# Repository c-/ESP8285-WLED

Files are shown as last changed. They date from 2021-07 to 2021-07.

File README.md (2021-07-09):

This is a WLED board built around an ESP-8285, designed to be milled on
a CNC.

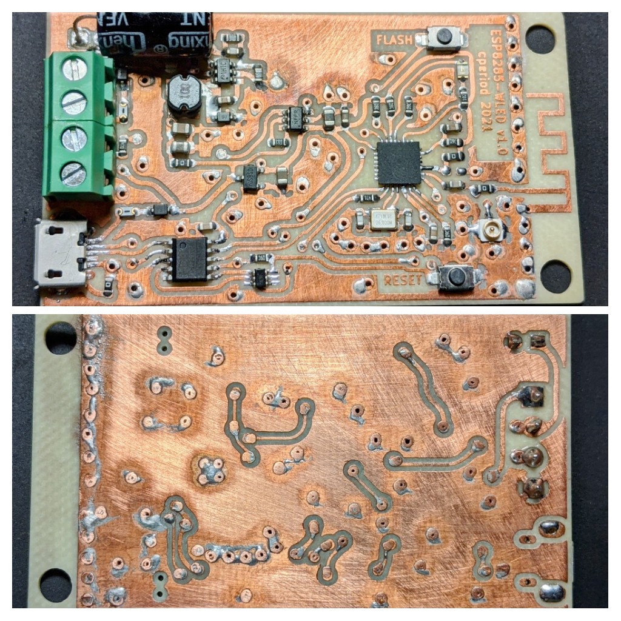
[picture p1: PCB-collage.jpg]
PCB Collage


Parts include the ESP8285, a PCB trace antenna, an optional external
antenna connector, CH340K USB controller (with support for ESP
auto-programming), TXS0101 level shifter, an ME3115
buck converter (for WS2811 projects), and a ME6211 3.3V LDO. This stuff
is, for the most part, straight out of the data sheets so there shouldn't
be anything too exciting.

There's no real attempt to do any antenna tuning, impedance matching, etc.
I used the D1 mini pro as a guideline and basically cross my fingers.

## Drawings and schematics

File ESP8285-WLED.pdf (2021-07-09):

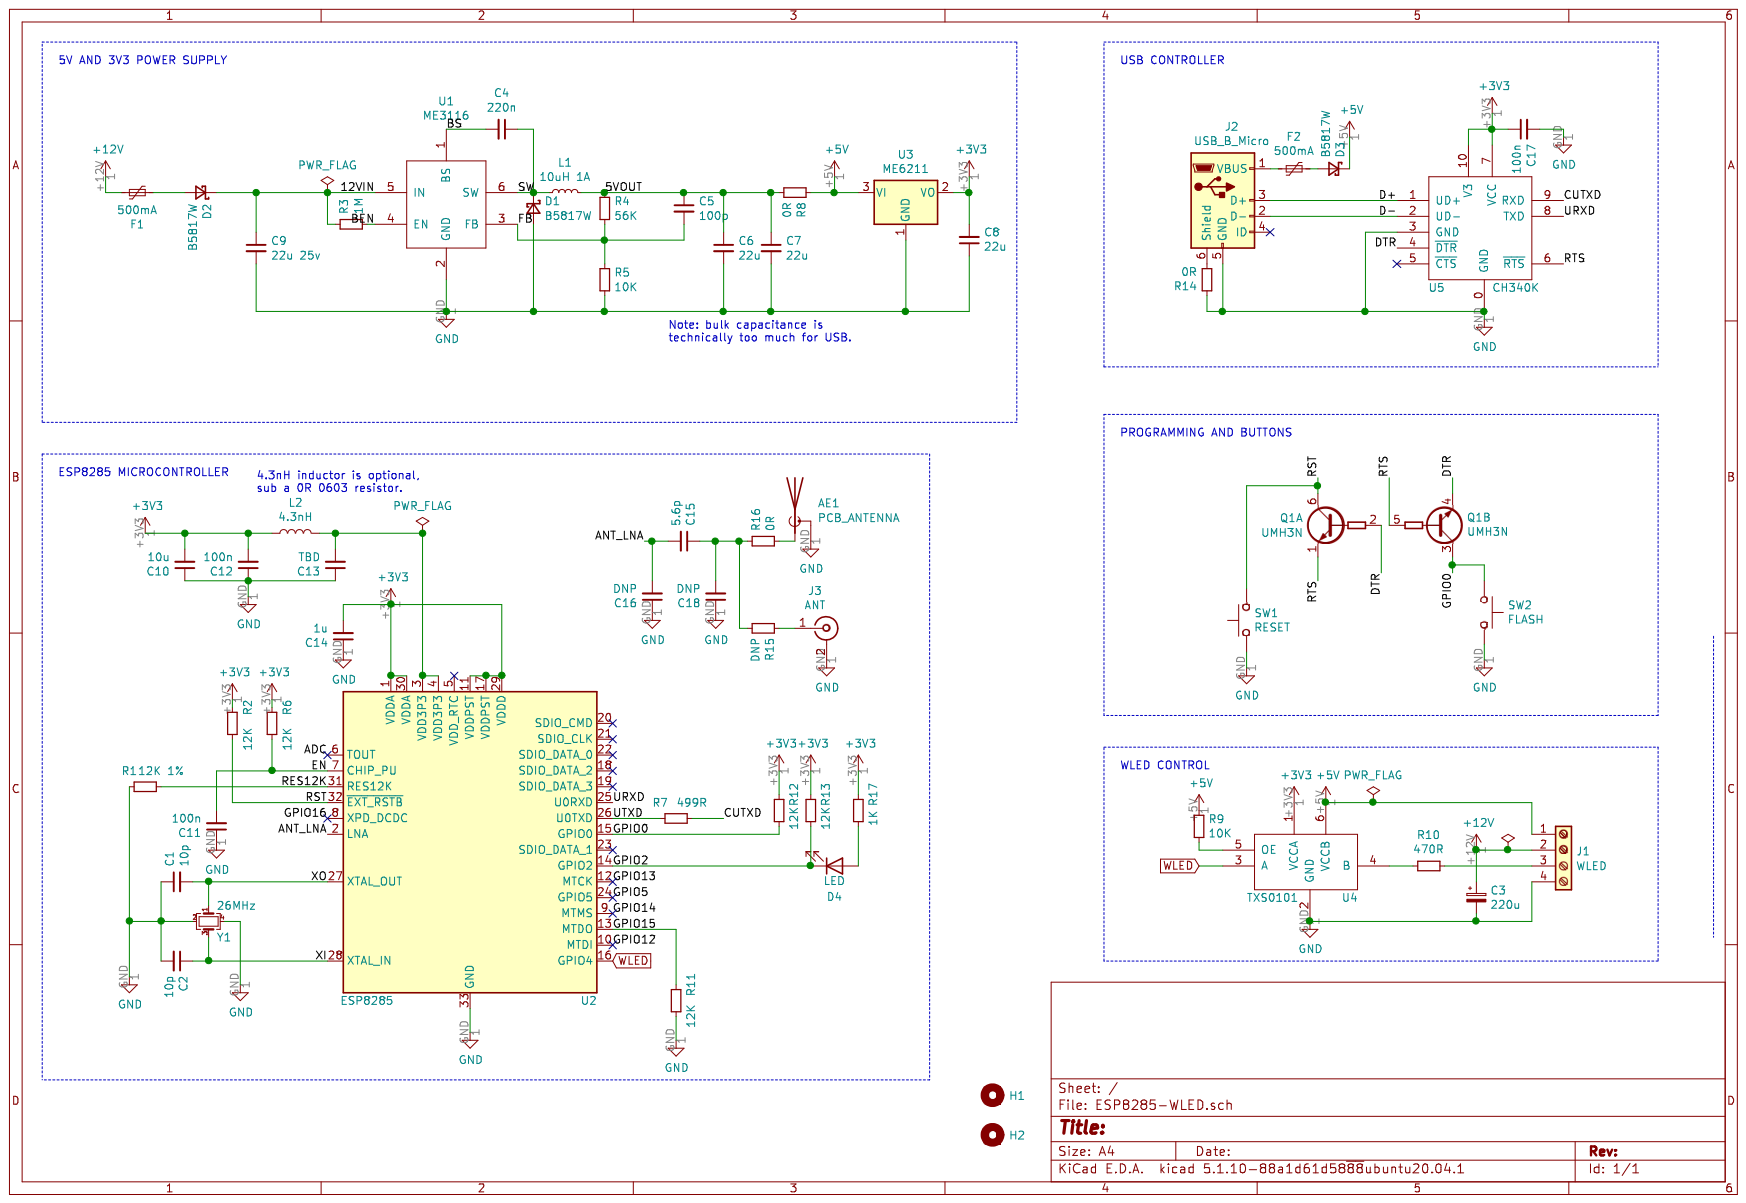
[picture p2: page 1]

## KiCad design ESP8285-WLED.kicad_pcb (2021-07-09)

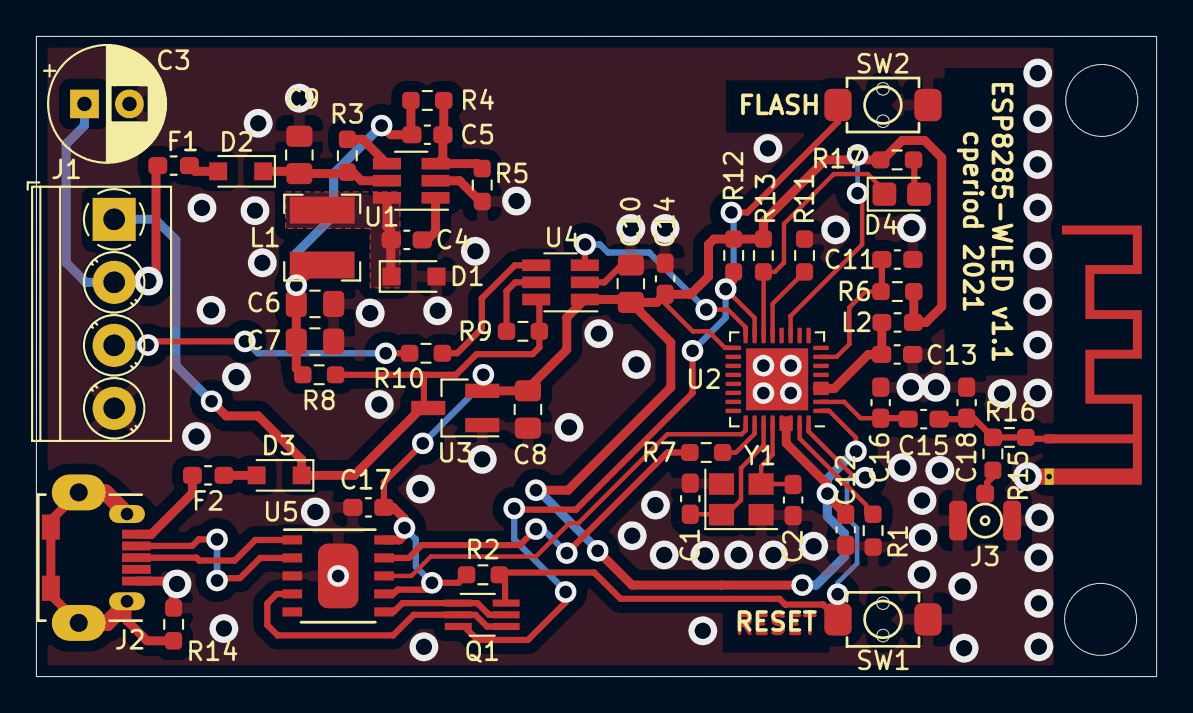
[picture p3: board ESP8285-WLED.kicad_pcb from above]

Board: 2 copper layers, 62.2 x 35.6 mm, 58 parts (0 on the bottom side), 39 nets.

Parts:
AE1: PCB_ANTENNA; Texas_SWRA117D_2.4GHz_Left
C1, C2: 10p; C_0603_1608Metric_Pad1.08x0.95mm_HandSolder
C3: 220u; CP_Radial_D6.3mm_P2.50mm
C4: 220n; C_0603_1608Metric_Pad1.08x0.95mm_HandSolder
C5: 100p; C_0603_1608Metric_Pad1.08x0.95mm_HandSolder
C6, C7, C8: 22u; C_0805_2012Metric_Pad1.18x1.45mm_HandSolder
C9: 22u 25v; C_0805_2012Metric_Pad1.18x1.45mm_HandSolder
C10: 10u; C_0805_2012Metric_Pad1.18x1.45mm_HandSolder
C11, C12, C17: 100n; C_0603_1608Metric_Pad1.08x0.95mm_HandSolder
C13: TBD; C_0603_1608Metric_Pad1.08x0.95mm_HandSolder
C14: 1u; C_0603_1608Metric_Pad1.08x0.95mm_HandSolder
C15: 5.6p; C_0603_1608Metric_Pad1.08x0.95mm_HandSolder
C16, C18: DNP; C_0603_1608Metric_Pad1.08x0.95mm_HandSolder
D1, D2, D3: B5817W; D_SOD-323_HandSoldering
D4: LED; LED_0805_2012Metric_Castellated
F1, F2: 500mA; Fuse_0603_1608Metric_Pad1.05x0.95mm_HandSolder
H1, H2: MountingHole; MountingHole_4mm
J1: WLED; TerminalBlock_Phoenix_PT-1,5-4-3.5-H_1x04_P3.50mm_Horizontal
J2: USB_B_Micro; USB_Micro-B_CNC_C10418
J3: ANT; IPX_Connector_C496552
L1: 10uH 1A; L_Bourns-SRN4018
L2: 4.3nH; L_0603_1608Metric_Pad1.05x0.95mm_HandSolder
Q1: UMH3N; SOT-363_SC-70-6_Handsoldering
R1: 12K 1%; R_0603_1608Metric_Pad0.98x0.95mm_HandSolder
R2, R6, R11, R12, R13: 12K; R_0603_1608Metric_Pad0.98x0.95mm_HandSolder
R3: 1M; R_0603_1608Metric_Pad0.98x0.95mm_HandSolder
R4: 56K; R_0603_1608Metric_Pad0.98x0.95mm_HandSolder
R5, R9: 10K; R_0603_1608Metric_Pad0.98x0.95mm_HandSolder
R7: 499R; R_0603_1608Metric_Pad0.98x0.95mm_HandSolder
R8, R14, R16: 0R; R_0603_1608Metric_Pad0.98x0.95mm_HandSolder
R10: 470R; R_0603_1608Metric_Pad0.98x0.95mm_HandSolder
R15: DNP; R_0603_1608Metric_Pad0.98x0.95mm_HandSolder
R17: 1K; R_0603_1608Metric_Pad0.98x0.95mm_HandSolder
SW1: RESET; SW_Tact_C354947
SW2: FLASH; SW_Tact_C354947
U1: ME3116; SOT-23-6_Handsoldering
U2: ESP8285; QFN-32-1EP_5x5mm_P0.5mm_EP3.45x3.45mm
U3: ME6211; SOT-23_Handsoldering
U4: TXS0101; SOT-23-6_Handsoldering
U5: CH340K; eSSOP-10_3.9x4.9mm_P1.00mm
Y1: 26MHz; Crystal_SMD_3225-4Pin_3.2x2.5mm

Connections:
+3V3: C8.2, C10.2, C12.2, C14.2, C17.1, L2.1, R2.2, R6.2, R12.2, R13.2, R17.2, U2.1, U2.11, U2.17, U2.29, U2.30, U3.2, U4.1, U5.7, U5.10
+5V: D3.1, J1.1, R8.1, R9.1, U3.3, U4.6
+12V: C3.1, F1.1, J1.2
/5VOUT: C5.1, C6.1, C7.1, L1.2, R4.1, R8.2
/12VIN: C9.1, D2.1, R3.1, U1.5
/ANT_LNA: C15.2, C16.2, U2.2
/BEN: R3.2, U1.4
/BS: C4.2, U1.1
/CUTXD: R7.1, U5.9
/D+: J2.3, U5.1
/D-: J2.2, U5.2
/DTR: Q1.2, Q1.4, U5.4
/EN: C11.2, R6.1, U2.7
/FB: C5.2, R4.2, R5.1, U1.3
/GPIO0: Q1.3, R12.1, SW2.1, U2.15
/GPIO2: D4.1, R13.1, U2.14
/GPIO15: R11.2, U2.13
/RES12K: R1.1, U2.31
/RST: Q1.6, R2.1, SW1.1, U2.32
/RTS: Q1.1, Q1.5, U5.6
/SW: C4.1, D1.1, L1.1, U1.6
/URXD: U2.25, U5.8
/UTXD: R7.2, U2.26
/XI: C2.1, U2.28, Y1.3
/XO: C1.2, U2.27, Y1.1
GND: AE1.2, C1.1, C2.2, C3.2, C6.2, C7.2, C8.1, C9.2, C10.1, C11.1, C12.1, C13.1, C14.1, C16.1, C17.2, C18.1, D1.2, J1.4, J2.5, J3.2, R1.2, R5.2, R11.1, R14.1, SW1.2, SW2.2, U1.2, U2.33, U3.1, U4.2, U5.0, U5.3, Y1.2, Y1.4
unnamed: AE1.1, R16.2
unnamed: C13.2, L2.2, U2.3, U2.4
unnamed: C15.1, C18.2, R15.2, R16.1
unnamed: D2.2, F1.2
unnamed: D3.2, F2.1
unnamed: D4.2, R17.1
unnamed: F2.2, J2.1
unnamed: J1.3, R10.1
unnamed: J2.6, R14.2
unnamed: J3.1, R15.1
unnamed: R9.2, U4.5
unnamed: R10.2, U4.4
WLED: U2.16, U4.3

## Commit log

2021-07-02 added antenna track width
2021-07-02 tweaking and cleanups
    [ESP8285-WLED.kicad_pcb]
2021-07-02 more tidying
    [ESP8285-WLED.kicad_pcb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]
2021-07-02 adjustments around the crystal
    [ESP8285-WLED.kicad_pcb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]
2021-07-02 more tweaking
    [ESP8285-WLED.kicad_pcb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]
2021-07-03 more adjustments
    [ESP8285-WLED.kicad_pcb]
2021-07-03 even more tweaks
    [ESP8285-WLED.kicad_pcb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]
2021-07-09 updates and tweaks based on actually building one
    [ESP8285-WLED.kicad_pcb, ESP8285-WLED.sch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]
2021-07-09 add a schematic pdf, minor doc tweaks
    [ESP8285-WLED.sch]
2021-07-09 warning about antenna
